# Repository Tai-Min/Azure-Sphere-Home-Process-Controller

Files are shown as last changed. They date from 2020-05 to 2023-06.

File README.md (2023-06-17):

# Azure Sphere Home Process Controller
My entry for [Home Is Where the Hack Is Challenge, with Avnet Azure Sphere](https://www.element14.com/community/docs/DOC-94716?CMP=e-email-ADH-e14-Com-170420-Avnet-2391) (Grand Prize winner!)

Industrial like PID / Two state process controller with web based configuration, MQTT communication and Azure IoT Central integration.

This repository contains source code for both High level application and real time core of Azure Sphere board, source codes for Arduino expansion cards, electronic design files for KiCad, housing design files for Autodesk Inventor and STL files for 3d printing.

For details how it was created and how to use it click [here](https://www.element14.com/community/groups/azuresphere/blog/2020/05/29/azure-sphere-home-process-controller)

Controller image

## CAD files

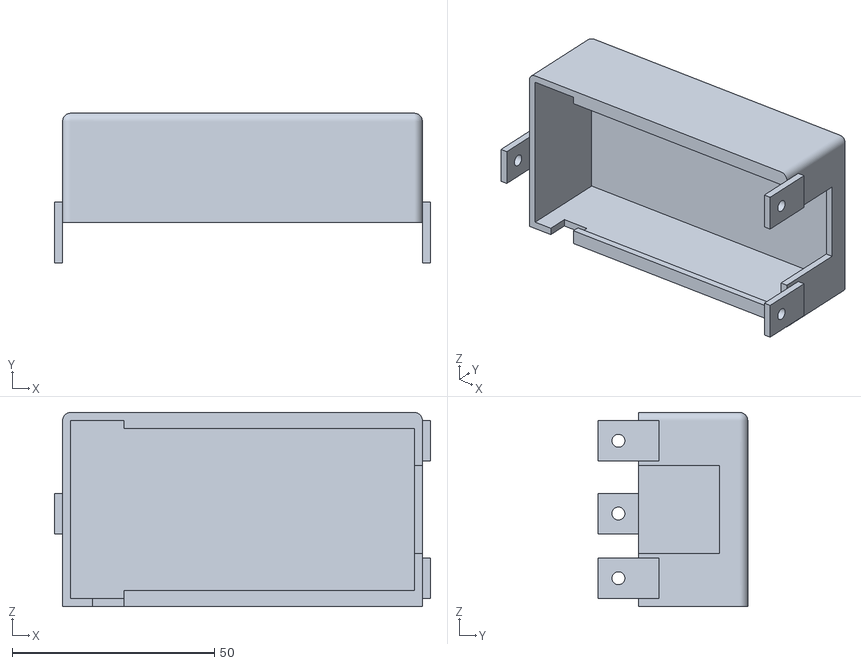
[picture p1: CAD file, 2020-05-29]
Addons/Input/case/stl/top.stl
93.0 x 37.0 x 48.0

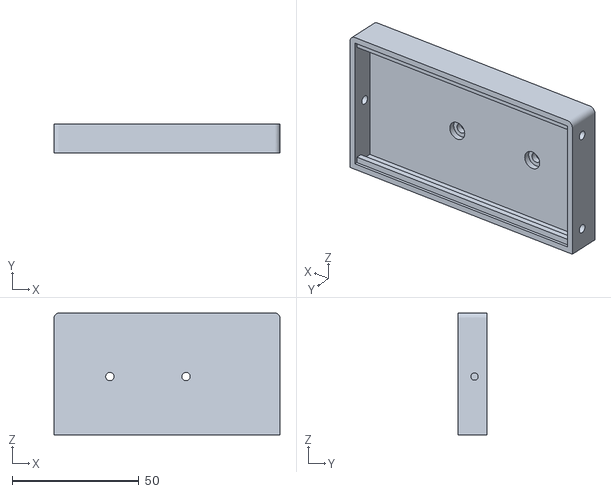
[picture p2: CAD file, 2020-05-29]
Addons/Output/case/stl/bottom.stl
89.0 x 11.6 x 48.0

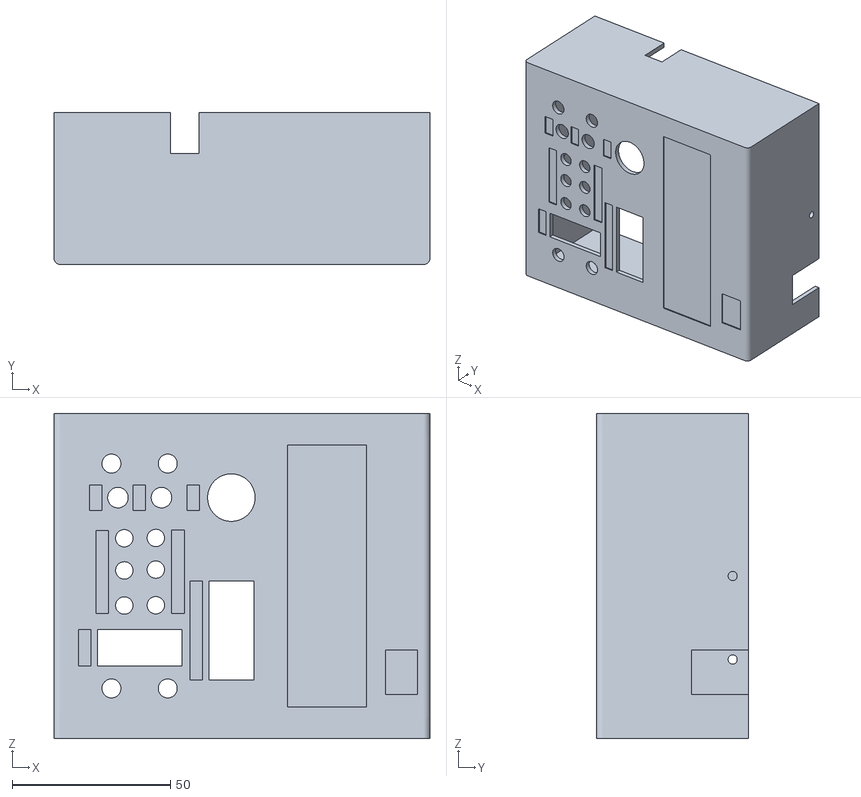
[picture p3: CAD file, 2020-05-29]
Controller/case/stl/case_top.stl
118.7 x 48.0 x 102.8

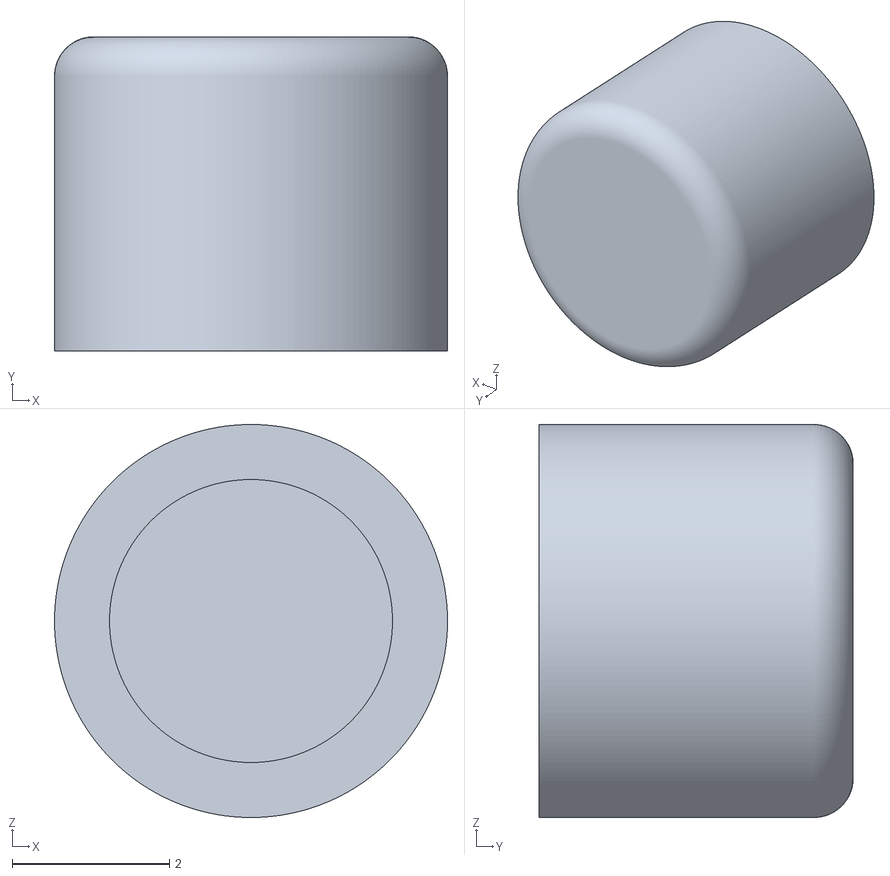
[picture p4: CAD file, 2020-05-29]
Controller/case/stl/button.stl
5.00 x 4.00 x 5.00

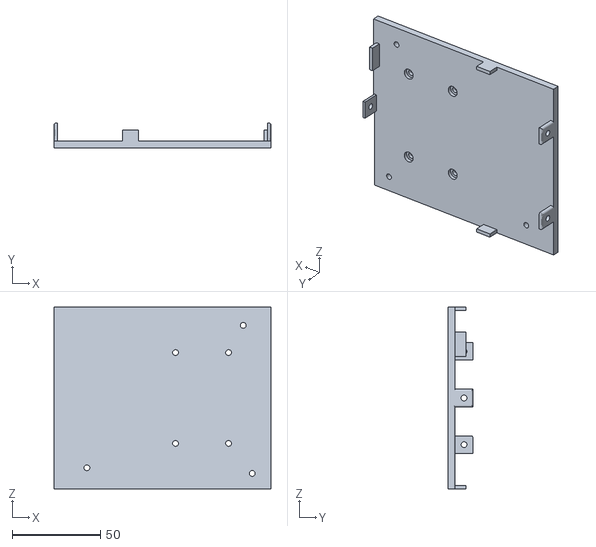
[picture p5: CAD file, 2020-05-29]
Controller/case/stl/case_bottom.stl
122.7 x 14.0 x 102.8

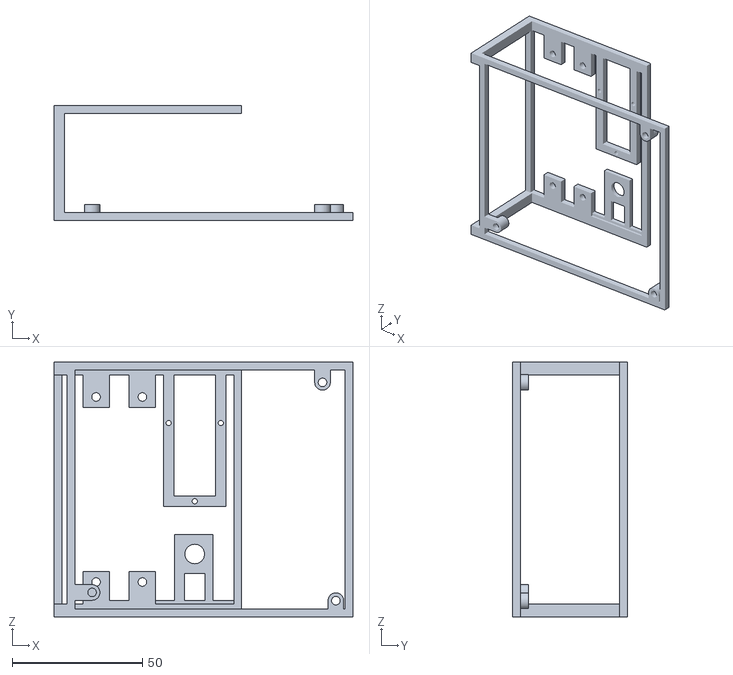
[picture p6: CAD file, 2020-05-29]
Controller/case/stl/electronic_holder.stl
114.7 x 44.0 x 97.7

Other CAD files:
Addons/Input/case/stl/bottom.stl
Addons/Output/case/stl/top.stl
Addons/Input/case/DIN_mount.ipt
Addons/Input/case/SHCS M3-20.ipt
Addons/Input/case/bottom.ipt
Addons/Input/case/input_assembly.iam
Addons/Input/case/top.ipt
Addons/Output/case/DIN_mount.ipt
Addons/Output/case/SHCS M3-20.ipt
Addons/Output/case/bottom.ipt
Addons/Output/case/output_assembly.iam
Addons/Output/case/top.ipt
Controller/case/4Digit_7Segment_LED_Display v8.ipt
Controller/case/BAR1_Fusion_sp_5EABBA22.ipt
Controller/case/Board_Geoms_8195.iam
Controller/case/D1_LED_D5.0mm_5EABBA34.ipt
Controller/case/D2_LED_D5.0mm_5EABBC42.ipt
Controller/case/D3_LED_D5.0mm_5EABBA58.ipt
Controller/case/D4_LED_D5.0mm_5EABBD40.ipt
Controller/case/D5_LED_D5.0mm_5EABBA7C.ipt
Controller/case/D6_LED_D5.0mm_5EABBA8E.ipt
Controller/case/DIN_mount.ipt
Controller/case/PCB_Sketch_8195.ipt
Controller/case/Pcb_8195.ipt
Controller/case/SHCS M3-20.ipt
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

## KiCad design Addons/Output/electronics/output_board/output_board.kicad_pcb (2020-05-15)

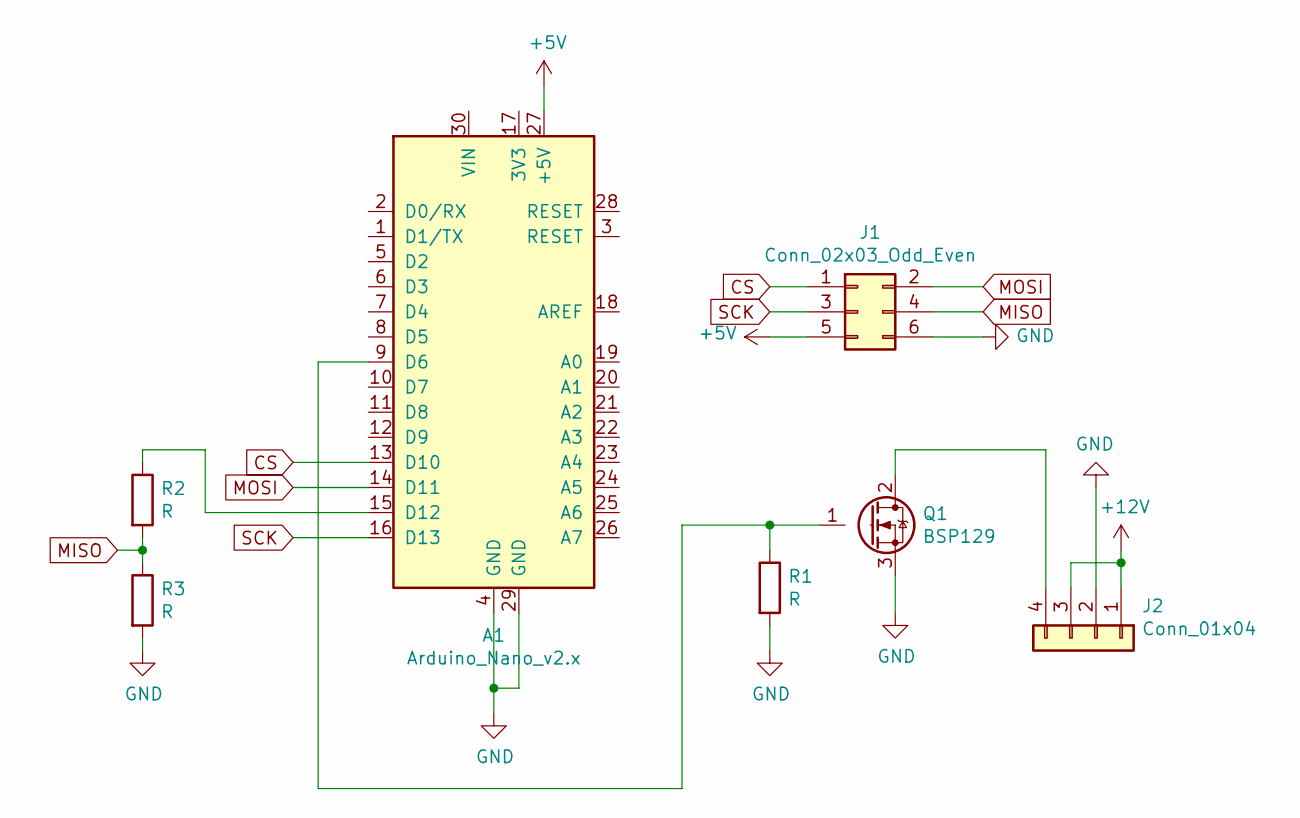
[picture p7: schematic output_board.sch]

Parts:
A1: Arduino_Nano_v2.x; Arduino_Nano
J1: Conn_02x03_Odd_Even; PinSocket_2x03_P2.54mm_Horizontal
J2: Conn_01x04; PhoenixContact_MSTBA_2,5_4-G-5,08_1x04_P5.08mm_Horizontal
Q1: BSP129; TO-220-3_Vertical
R1, R2, R3: R; R_Axial_DIN0207_L6.3mm_D2.5mm_P10.16mm_Horizontal

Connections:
+5V: A1.27 (+5V), J1.5
+12V: J2.1, J2.3
CS: A1.13 (D10), J1.1
GND: A1.4 (GND), A1.29 (GND), J1.6, J2.2, Q1.3 (S), R1.2, R3.2
MISO: J1.4, R2.2, R3.1
MOSI: A1.14 (D11), J1.2
unnamed: A1.9 (D6), Q1.1 (G), R1.1
unnamed: A1.15 (D12), R2.1
unnamed: J2.4, Q1.2 (D)
SCK: A1.16 (D13), J1.3

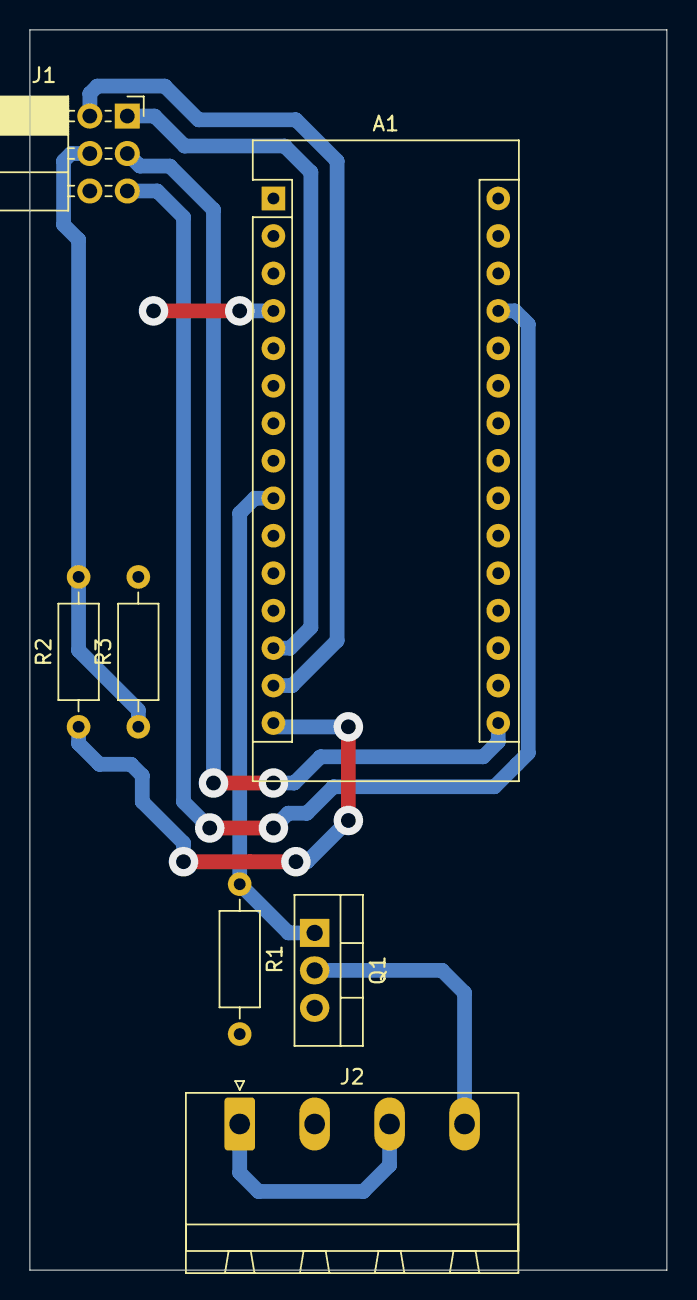
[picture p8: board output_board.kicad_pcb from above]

Board: 2 copper layers, 43.2 x 84.1 mm, 7 parts (0 on the bottom side), 10 nets.

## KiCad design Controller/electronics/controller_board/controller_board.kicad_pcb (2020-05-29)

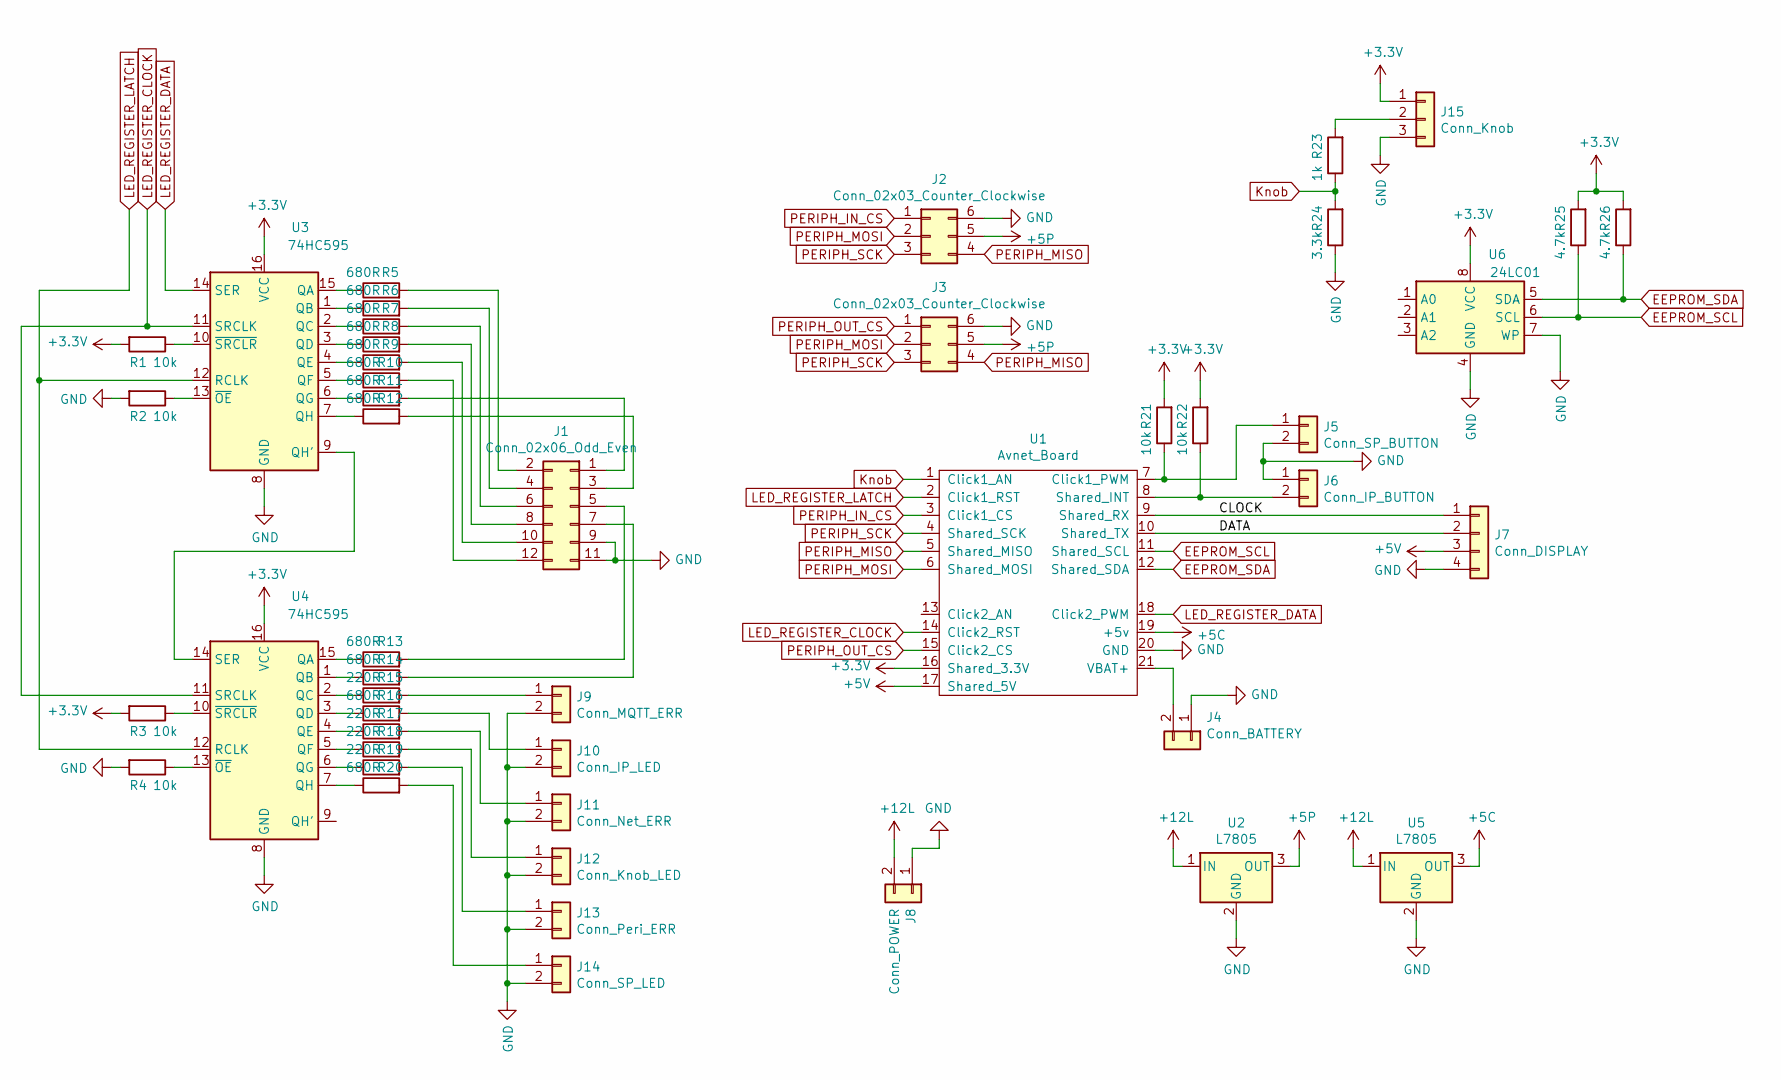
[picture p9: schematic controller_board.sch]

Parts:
J1: Conn_02x06_Odd_Even; PinHeader_2x06_P2.54mm_Vertical
J2: Conn_02x03_Counter_Clockwise; PinSocket_2x03_P2.54mm_Horizontal
J3: Conn_02x03_Counter_Clockwise; PinHeader_2x03_P2.54mm_Horizontal
J4: Conn_BATTERY; PinHeader_1x02_P2.54mm_Vertical
J5: Conn_SP_BUTTON; PinHeader_1x02_P2.54mm_Vertical
J6: Conn_IP_BUTTON; PinHeader_1x02_P2.54mm_Vertical
J7: Conn_DISPLAY; PinHeader_1x04_P2.54mm_Vertical
J8: Conn_POWER; PhoenixContact_MSTBA_2,5_2-G_1x02_P5.00mm_Horizontal
J9: Conn_MQTT_ERR; PinHeader_1x02_P2.54mm_Vertical
J10: Conn_IP_LED; PinHeader_1x02_P2.54mm_Vertical
J11: Conn_Net_ERR; PinHeader_1x02_P2.54mm_Vertical
J12: Conn_Knob_LED; PinHeader_1x02_P2.54mm_Vertical
J13: Conn_Peri_ERR; PinHeader_1x02_P2.54mm_Vertical
J14: Conn_SP_LED; PinHeader_1x02_P2.54mm_Vertical
J15: Conn_Knob; PinHeader_1x03_P2.54mm_Vertical
R1, R2, R3, R4, R21, R22: 10k; R_Axial_DIN0207_L6.3mm_D2.5mm_P10.16mm_Horizontal
R5, R6, R7, R8, R9, R10, R11, R12, R13, R14, R16, R20: 680R; R_Axial_DIN0207_L6.3mm_D2.5mm_P10.16mm_Horizontal
R15, R17, R18, R19: 220R; R_Axial_DIN0207_L6.3mm_D2.5mm_P10.16mm_Horizontal
R23: 1k; R_Axial_DIN0207_L6.3mm_D2.5mm_P10.16mm_Horizontal
R24: 3.3k; R_Axial_DIN0207_L6.3mm_D2.5mm_P10.16mm_Horizontal
R25, R26: 4.7k; R_Axial_DIN0207_L6.3mm_D2.5mm_P10.16mm_Horizontal
U1: Avnet_Board; Avnet_Azure_Sphere
U2, U5: L7805; TO-220-3_Vertical
U3, U4: 74HC595; DIP-16_W7.62mm_LongPads
U6: 24LC01; DIP-8_W7.62mm_LongPads

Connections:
+3V3: J15.1, R1.2, R3.2, R21.2, R22.2, R25.2, R26.2, U1.16 (Shared_3.3V), U3.16 (VCC), U4.16 (VCC), U6.8 (VCC)
+5C: U1.19 (+5v), U5.3 (OUT)
+5P: J2.5, J3.5, U2.3 (OUT)
+5V: J7.3, U1.17 (Shared_5V)
+12L: J8.2, U2.1 (IN), U5.1 (IN)
/CLOCK: J7.1, U1.9 (Shared_RX)
/DATA: J7.2, U1.10 (Shared_TX)
EEPROM_SCL: R25.1, U1.11 (Shared_SCL), U6.6 (SCL)
EEPROM_SDA: R26.1, U1.12 (Shared_SDA), U6.5 (SDA)
GND: J1.9, J1.11, J2.6, J3.6, J4.1, J5.2, J6.1, J7.4, J8.1, J9.2, J10.2, J11.2, J12.2, J13.2, J14.2, J15.3, R2.2, R4.2, R24.1, U1.20 (GND), U2.2 (GND), U3.8 (GND), U4.8 (GND), U5.2 (GND), U6.4 (GND), U6.7 (WP)
Knob: R23.1, R24.2, U1.1 (Click1_AN)
LED_REGISTER_CLOCK: U1.14 (Click2_RST), U3.11 (SRCLK), U4.11 (SRCLK)
LED_REGISTER_DATA: U1.18 (Click2_PWM), U3.14 (SER)
LED_REGISTER_LATCH: U1.2 (Click1_RST), U3.12 (RCLK), U4.12 (RCLK)
unnamed: J1.1, R11.2
unnamed: J1.2, R5.2
unnamed: J1.3, R12.2
unnamed: J1.4, R6.2
unnamed: J1.5, R13.2
unnamed: J1.6, R7.2
unnamed: J1.7, R14.2
unnamed: J1.8, R8.2
unnamed: J1.10, R9.2
unnamed: J1.12, R10.2
unnamed: J4.2, U1.21 (VBAT+)
unnamed: J5.1, R21.1, U1.7 (Click1_PWM)
unnamed: J6.2, R22.1, U1.8 (Shared_INT)
unnamed: J9.1, R15.2
unnamed: J10.1, R16.2
unnamed: J11.1, R17.2
unnamed: J12.1, R18.2
unnamed: J13.1, R19.2
unnamed: J14.1, R20.2
unnamed: J15.2, R23.2
unnamed: R1.1, U3.10 (~SRCLR)
unnamed: R2.1, U3.13 (~OE)
unnamed: R3.1, U4.10 (~SRCLR)
unnamed: R4.1, U4.13 (~OE)
unnamed: R5.1, U3.15 (QA)
unnamed: R6.1, U3.1 (QB)
unnamed: R7.1, U3.2 (QC)
unnamed: R8.1, U3.3 (QD)
unnamed: R9.1, U3.4 (QE)
unnamed: R10.1, U3.5 (QF)
unnamed: R11.1, U3.6 (QG)
unnamed: R12.1, U3.7 (QH)
unnamed: R13.1, U4.15 (QA)
unnamed: R14.1, U4.1 (QB)
unnamed: R15.1, U4.2 (QC)
unnamed: R16.1, U4.3 (QD)
unnamed: R17.1, U4.4 (QE)
unnamed: R18.1, U4.5 (QF)
unnamed: R19.1, U4.6 (QG)
unnamed: R20.1, U4.7 (QH)
unnamed: U3.9 (QH'), U4.14 (SER)
PERIPH_IN_CS: J2.1, U1.3 (Click1_CS)
PERIPH_MISO: J2.4, J3.4, U1.5 (Shared_MISO)
PERIPH_MOSI: J2.2, J3.2, U1.6 (Shared_MOSI)
PERIPH_OUT_CS: J3.1, U1.15 (Click2_CS)
PERIPH_SCK: J2.3, J3.3, U1.4 (Shared_SCK)

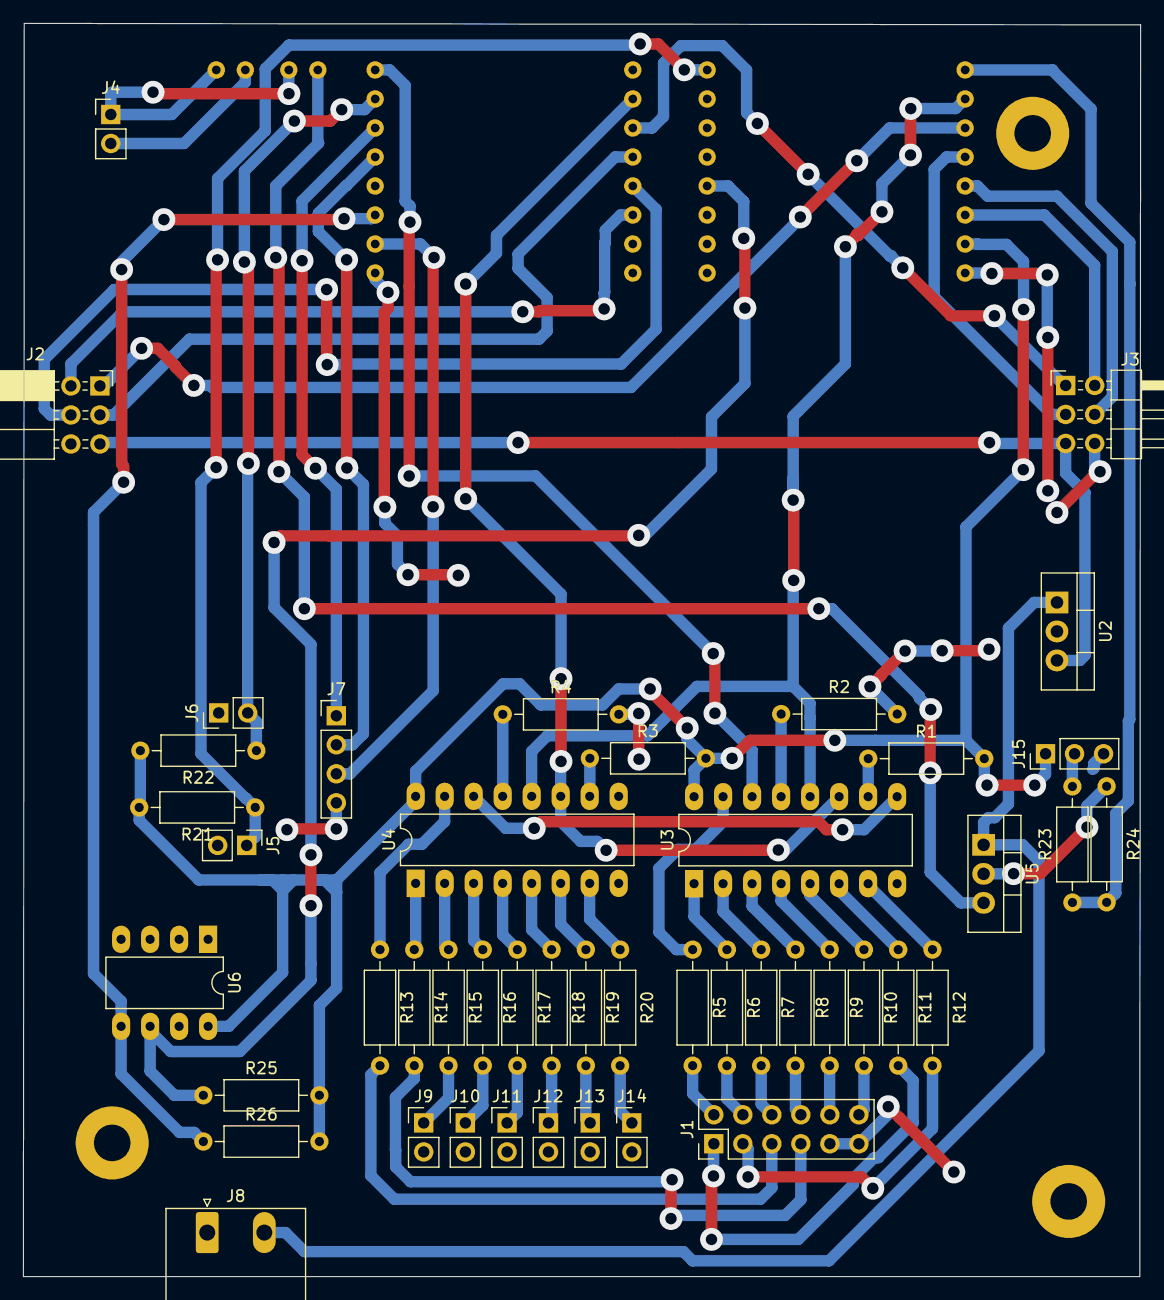
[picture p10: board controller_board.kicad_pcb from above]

Board: 2 copper layers, 97.8 x 109.7 mm, 50 parts (1 on the bottom side), 60 nets.

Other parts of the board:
 : MountingHole_3.2mm_M3_Pad
  : MountingHole_3.2mm_M3_Pad
 #2: MountingHole_3.2mm_M3_Pad

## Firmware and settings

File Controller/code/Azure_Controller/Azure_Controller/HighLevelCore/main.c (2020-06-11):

#include <ctype.h>
#include <string.h>
#include <stdio.h>
#include <signal.h>
#include <errno.h>
#include <stdlib.h>

#include "applibs_versions.h"
#include <applibs/log.h>
#include <applibs/networking.h>

#include "eventloop_timer_utilities.h"

#include "common.h"
#include "mqtt_utilities.h"
#include "http_utilities.h"
#include "mailbox_utilities.h"
#include "network_utilities.h"
#include "config_structs.h"
#include "website.h"
#include "cloud.h"


#define MQTT_PUBLISH_PERIOD 10
#define CLOUD_PUBLISH_PERIOD 60 

typedef enum {
    ExitCode_Success = 0,
    ExitCode_TermHandler_SigTerm = 1,
    ExitCode_TimerHandler_Consume = 2,
    ExitCode_Init_EventLoop = 3,
    ExitCode_Init_Timer = 4,
    ExitCode_Main_EventLoopFail = 5,
    ExitCode_Init_Mailbox = 6,
    ExitCode_Init_HTTP =7
} ExitCode;

static EventLoop* eventLoop = NULL;
static volatile sig_atomic_t exitCode = ExitCode_Success;

int main(int argc, char* argv[]);

/**
* @brief Signal handler for termination requests.
* 
* @param signalNumber Unused.
*/
static void TerminationHandler(int signalNumber);

/**
* @brief Init event loop, timers, mailbox and http server.
*
* @return ExitCode_Success on success, other ExitCode on failure.
*/
static ExitCode InitHandlers(void);

/**
* @brief Close event loop, dispose timers, close MQTT, HTTP server and mailbox.
*/
static void CloseHandlers(void);

/* cloud */
/**
* @brief Periodically called to send diagnostic info to Azure cloud services.
*
* @param timer Pointer to timer to consume and restart.
*/
static void cloudPublishTimerEventHandler(EventLoopTimer* timer);
static EventLoopTimer* publishCloudMsgTimer = NULL;
static int telemetryCount = 0;
static struct timespec azureTelemetryPeriod;

/* website */
/**
* @brief Callback received from HTTP server when GET method has been received.
*
* @param siteLocation String that contains site location. i.e /config.
* @param argKeys Keys from key-value pair passed to GET method after ? symbol.
* @param argValues Values from key-value pair passed to GET method after ? symbol.
* @return Pointer to internal buffer that holds website data to be sent to client.
*/
static const char* HTTP_GET_MethodCallback(char siteLocation[21], bool hasParams, char argKeys[20][31], char argValues[20][31]);

/**
* @brief Parse params received from GET request
*
* @param argKeys Keys from key-value pair passed to GET method after ? symbol.
* @param argValues Values from key-value pair passed to GET method after ? symbol.
*/
static void parseGETParams(char argKeys[20][31], char argValues[20][31]);

/* mqtt */
/**
* @brief Periodically called to send setpoint and process value to MQTT broker.
*
* @param timer Pointer to timer to consume and restart.
*/
static void mqttPublishTimerEventHandler(EventLoopTimer* timer);

/**
* @brief Called when device receives data from subscribed setpoint topic.
* 
* @param topic Name of topic from which message has come.
* @param msg Message.
*/
static void mqttSubscribeCallback(char* topic, char* msg);
static EventLoopTimer* publishMQTTMsgTimer = NULL;
static struct MQTTConfig mqttConf = {
    .processValueTopic = "\0",
    .setpointTopic = "\0",
    .brokerIPAddress = "\0"
};
static bool reloadMQTT = false;

int main(int argc, char*argv[])
{
    if (argc > 1) {
        setCloudScopeId(argv[1]);
    }
    else {
        Log_Debug("Cloud scope is required to run this application.\n");
        return -1;
    }

    waitMs(2000);// wait a bit for real time core to set up stuff

    signal(SIGPIPE, SIG_IGN);

    exitCode = InitHandlers();

    while (exitCode == ExitCode_Success) {
        EventLoop_Run_Result result = EventLoop_Run(eventLoop, -1, true);

        // errno in case of breakpoint
        if (result == EventLoop_Run_Failed && errno != EINTR) {
            exitCode = ExitCode_Main_EventLoopFail;
        }
    }

    CloseHandlers();
    Log_Debug("Application exiting\n");
    return exitCode;
}

static void TerminationHandler(int signalNumber)
{
    exitCode = ExitCode_TermHandler_SigTerm;
}

static ExitCode InitHandlers(void)
{
    struct sigaction action;
    memset(&action, 0, sizeof(struct sigaction));
    action.sa_handler = TerminationHandler;
    sigaction(SIGTERM, &action, NULL);

    eventLoop = EventLoop_Create();
    if (eventLoop == NULL) {
        Log_Debug("Could not create event loop.\n");
        return ExitCode_Init_EventLoop;
    }

    // Callback for MQTT subscribe
    MQTTRegisterSubscribeCallback(mqttSubscribeCallback);

    // Init config http server
    if (httpServerInit() == -1) {
        return ExitCode_Init_HTTP;
    }
    registerGETCallback(HTTP_GET_MethodCallback);

    // Init communication with RT Core
    if (mailboxInit() == -1) {
        return ExitCode_Init_Mailbox;
    }

    // Register a ten second timer to publish setpoint and pv to mqtt broker
    static const struct timespec sendPeriodMQTT = { .tv_sec = MQTT_PUBLISH_PERIOD, .tv_nsec = 0 };
    publishMQTTMsgTimer = CreateEventLoopPeriodicTimer(eventLoop, &mqttPublishTimerEventHandler, &sendPeriodMQTT);
    if (publishMQTTMsgTimer == NULL) {
        return ExitCode_Init_Timer;
    }

    // Register timer to send data to cloud
    azureTelemetryPeriod.tv_sec = getCloudPollPeriodSeconds();
    publishCloudMsgTimer = CreateEventLoopPeriodicTimer(eventLoop, &cloudPublishTimerEventHandler, &azureTelemetryPeriod);
    if (publishCloudMsgTimer == NULL) {
        return ExitCode_Init_Timer;
    }

    return ExitCode_Success;
}

static void CloseHandlers(void)
{
    DisposeEventLoopTimer(publishMQTTMsgTimer);
    DisposeEventLoopTimer(publishCloudMsgTimer);

    EventLoop_Close(eventLoop);

    MQTTStop();
    MQTTKillSubthread();
    httpServerStop();
    httpServerKillSubthread();
    mailboxStop();
}

static void cloudPublishTimerEventHandler(EventLoopTimer* timer) {
    if (ConsumeEventLoopTimerEvent(timer) != 0) {
        exitCode = ExitCode_TimerHandler_Consume;
        return;
    }

    bool isNetworkReady = false;
    if (Networking_IsNetworkingReady(&isNetworkReady) != -1) {
        if (isNetworkReady && !isCloudAuthenticated()) {
            SetupAzureClient();
        }
    }

    if (isCloudAuthenticated()) {
        telemetryCount++;
        if (telemetryCount == CLOUD_PUBLISH_PERIOD) {
            telemetryCount = 0;
            char telemetryBuf[128];
            double sp, pv;
            getSpPv(&sp, &pv);
            snprintf(telemetryBuf, 128, "{\"Setpoint\": \"%f\", \"ProcessValue\": \"%f\"}", sp, pv);
            sendTelemetryToCloud(telemetryBuf);
        }
        doCloudLLWork();
    }
    else {
    }

    // update telemetry period
    azureTelemetryPeriod.tv_sec = getCloudPollPeriodSeconds();
    SetEventLoopTimerPeriod(timer, &azureTelemetryPeriod);
}

static const char* HTTP_GET_MethodCallback(char siteLocation[21], bool hasParams, char argKeys[20][31], char argValues[20][31]) {
    static char buf[4096];
    Log_Debug("GET callback\n");
    Log_Debug("%s\n", siteLocation);
    if (strcmp(siteLocation, "/config") == 0) {
        Log_Debug("config website\n");

        if (hasParams) {
            parseGETParams(argKeys, argValues);
        }

        double sp, pv;
        getSpPv(&sp, &pv);
        struct MQTTConfig mqttConf = mqttConfigLoad();
        struct InputPeriphConfig iconf;
        struct OutputPeriphConfig oconf;
        struct ControllerConfig cconf;
        controlConfigLoad(&iconf, &oconf, &cconf);
        const char* selectedNONE = cconf.controllerType == NONE ? "selected=\"selected\"" : "";
        const char* selectedPID = cconf.controllerType == PID ? "selected=\"selected\"" : "";
        const char* selectedTS = cconf.controllerType == TWO_STATE ? "selected=\"selected\"" : "";
        Log_Debug("IF name: %s\n", getSavedNetworkInterfaceName());
        snprintf(buf, 4096, page, sp,getSavedNetworkInterfaceName(),"111111",mqttConf.brokerIPAddress,mqttConf.setpointTopic,mqttConf.processValueTopic,
            iconf.inputMinValue,iconf.inputMaxValue,oconf.outputMinValue,oconf.outputMaxValue,selectedNONE, selectedTS,selectedPID, 
            cconf.controllerConfig.twoStateConfig.bottomSwitchBoundary, cconf.controllerConfig.twoStateConfig.topSwitchBoundary,
            cconf.controllerConfig.twoStateConfig.offValue, cconf.controllerConfig.twoStateConfig.onValue,
            cconf.controllerConfig.PIDConfig.kp, cconf.controllerConfig.PIDConfig.ki, cconf.controllerConfig.PIDConfig.kd,
            cconf.controllerConfig.PIDConfig.saturationLower, cconf.controllerConfig.PIDConfig.saturarionUpper);
    }
    else {
        Log_Debug("other website\n");
        memcpy(buf, nfound, strlen(nfound)+1);
        
    }
    return buf;
}


static void parseGETParams(char argKeys[20][31], char argValues[20][31]) {

    struct MQTTConfig mqttConf = mqttConfigLoad();
    struct InputPeriphConfig iconf;
    struct OutputPeriphConfig oconf;
    struct ControllerConfig cconf;
    char ssid[31] = "USER_NET\0";
    char psk[31] = "12345678\0";
    bool setWIFI = false;

    for (uint8_t i = 0; i < 20; i++) {
        if (strcmp(argKeys[i], "setpoint") == 0) {
            setSp(atof(argValues[i]));
        }
        else if (strcmp(argKeys[i], "ssid") == 0) {
            memcpy(ssid, argValues[i], strlen(argValues[i]) + 1);
            //Log_Debug("Received IF name: %s\n", ssid);
        }
        else if (strcmp(argKeys[i], "psk") == 0) {
            if (strcmp(argValues[i], "111111") != 0) {
                memcpy(psk, argValues[i], strlen(argValues[i]) + 1);
                setWIFI = true;
            }
        }
        else if (strcmp(argKeys[i], "brokerip") == 0) {
            memcpy(mqttConf.brokerIPAddress, argValues[i], strlen(argValues[i])+1);
        }
        else if (strcmp(argKeys[i], "sptopic") == 0) {
            memcpy(mqttConf.setpointTopic, argValues[i], strlen(argValues[i]) + 1);
        }
        else if (strcmp(argKeys[i], "pvtopic") == 0) {
            memcpy(mqttConf.processValueTopic, argValues[i], strlen(argValues[i]) + 1);
        }
        else if (strcmp(argKeys[i], "inputmin") == 0) {
            iconf.inputMinValue = atof(argValues[i]);
        }
        else if (strcmp(argKeys[i], "inputmax") == 0) {
            iconf.inputMaxValue = atof(argValues[i]);
        }
        else if (strcmp(argKeys[i], "outputmin") == 0) {
            oconf.outputMinValue = atof(argValues[i]);
        }
        else if (strcmp(argKeys[i], "outputmax") == 0) {
            oconf.outputMaxValue = atof(argValues[i]);
        }
        else if (strcmp(argKeys[i], "selectedcontroller") == 0) {
            if (strcmp(argValues[i], "None") == 0)
                cconf.controllerType = NONE;
            if (strcmp(argValues[i], "Two+State") == 0) {
                cconf.controllerType = TWO_STATE;
                for (uint8_t j = 0; j < 20; j++) {
                    if (strcmp(argKeys[j], "tstoggleoff") == 0) {
                        cconf.controllerConfig.twoStateConfig.bottomSwitchBoundary = atof(argValues[j]);
                    }
                    else if (strcmp(argKeys[j], "tstoggleon") == 0) {
                        cconf.controllerConfig.twoStateConfig.topSwitchBoundary = atof(argValues[j]);
                    }
                    else if (strcmp(argKeys[j], "tsoffoutput") == 0) {
                        cconf.controllerConfig.twoStateConfig.offValue = atof(argValues[j]);
                    }
                    else if (strcmp(argKeys[j], "tsonoutput") == 0) {
                        cconf.controllerConfig.twoStateConfig.onValue = atof(argValues[j]);
                    }
                }
            }
            if (strcmp(argValues[i], "PID") == 0) {
                cconf.controllerType = PID;
                for (uint8_t j = 0; j < 20; j++) {
                    if (strcmp(argKeys[j], "pidkp") == 0) {
                        cconf.controllerConfig.PIDConfig.kp = atof(argValues[j]);
                    }
                    else if (strcmp(argKeys[j], "pidki") == 0) {
                        cconf.controllerConfig.PIDConfig.ki = atof(argValues[j]);
                    }
                    else if (strcmp(argKeys[j], "pidkd") == 0) {
                        cconf.controllerConfig.PIDConfig.kd = atof(argValues[j]);
                    }
                    else if (strcmp(argKeys[j], "pidlowsat") == 0) {
                        cconf.controllerConfig.PIDConfig.saturationLower = atof(argValues[j]);
                    }
                    else if (strcmp(argKeys[j], "pidupsat") == 0) {
                        cconf.controllerConfig.PIDConfig.saturarionUpper = atof(argValues[j]);
                    }
                }
            }
        }
    }
    mqttConfigSave(mqttConf);
    reloadMQTT = true;
    controlConfigSave(iconf, oconf, cconf);
    if (setWIFI)
        updateUserDefinedNetwork(ssid, psk);
}

static void mqttPublishTimerEventHandler(EventLoopTimer* timer)
{
    if (ConsumeEventLoopTimerEvent(timer) != 0) {
        exitCode = ExitCode_TimerHandler_Consume;
        return;
    }

    if (!isNetworkConnected()) {
        mqttErrorSet();
        networkErrorSet();
        MQTTStop();
        return;
    }
    else {
        ipAddressKeep(getIPAddress());
        networkErrorClear();
    }

    if (!strcmp(mqttConf.brokerIPAddress, "")) {
        mqttConf = mqttConfigLoad();
        Log_Debug("MQTT config loaded as: SP topic: %s, PV topic: %s, Broker ip: %s\n", mqttConf.setpointTopic, mqttConf.processValueTopic, mqttConf.brokerIPAddress);
    }

    if (reloadMQTT) {
        MQTTStop();
        mqttConf = mqttConfigLoad();
        reloadMQTT = false;
        waitMs(50);
    }

    if (!MQTTIsActiveConnection()) {
        int res = MQTTInit(mqttConf.brokerIPAddress, "1883", mqttConf.setpointTopic);
        if (res) {
            mqttErrorSet();
            return;
        }
        mqttErrorClear();
        waitMs(50);
    }

    double sp, pv;
    getSpPv(&sp, &pv);
    char buf[100];
    snprintf(buf, 100, "%f", sp);
    if (MQTTPublish(mqttConf.setpointTopic, buf) != 0) {
        mqttErrorSet();
        MQTTStop();
    }

    snprintf(buf, 100, "%f", pv);
    if (MQTTPublish(mqttConf.processValueTopic, buf) != 0) {
        mqttErrorSet();
        MQTTStop();
    }
    else {
        mqttErrorClear();
    }
}

static void mqttSubscribeCallback(char* topic, char* msg) {
    if (strcmp(topic, mqttConf.setpointTopic) == 0) {
        setSp(atof(msg));
    }
}

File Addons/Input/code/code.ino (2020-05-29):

#include "pins_arduino.h"
#include <HCSR04.h>

#define BYTES_PER_FRAME 6
#define NUMBER_OF_INPUTS 1

int triggerPin = 3;
int echoPin = 4;
UltraSonicDistanceSensor distanceSensor(triggerPin, echoPin);
#define DISTANCE_MAX_CM 31.0
#define DISTANCE_MIN_CM 0.0

static const uint16_t crctable[256] =
{
  0x0000, 0x1189, 0x2312, 0x329B, 0x4624, 0x57AD, 0x6536, 0x74BF,
  0x8C48, 0x9DC1, 0xAF5A, 0xBED3, 0xCA6C, 0xDBE5, 0xE97E, 0xF8F7,
  0x0919, 0x1890, 0x2A0B, 0x3B82, 0x4F3D, 0x5EB4, 0x6C2F, 0x7DA6,
  0x8551, 0x94D8, 0xA643, 0xB7CA, 0xC375, 0xD2FC, 0xE067, 0xF1EE,
  0x1232, 0x03BB, 0x3120, 0x20A9, 0x5416, 0x459F, 0x7704, 0x668D,
  0x9E7A, 0x8FF3, 0xBD68, 0xACE1, 0xD85E, 0xC9D7, 0xFB4C, 0xEAC5,
  0x1B2B, 0x0AA2, 0x3839, 0x29B0, 0x5D0F, 0x4C86, 0x7E1D, 0x6F94,
  0x9763, 0x86EA, 0xB471, 0xA5F8, 0xD147, 0xC0CE, 0xF255, 0xE3DC,
  0x2464, 0x35ED, 0x0776, 0x16FF, 0x6240, 0x73C9, 0x4152, 0x50DB,
  0xA82C, 0xB9A5, 0x8B3E, 0x9AB7, 0xEE08, 0xFF81, 0xCD1A, 0xDC93,
  0x2D7D, 0x3CF4, 0x0E6F, 0x1FE6, 0x6B59, 0x7AD0, 0x484B, 0x59C2,
  0xA135, 0xB0BC, 0x8227, 0x93AE, 0xE711, 0xF698, 0xC403, 0xD58A,
  0x3656, 0x27DF, 0x1544, 0x04CD, 0x7072, 0x61FB, 0x5360, 0x42E9,
  0xBA1E, 0xAB97, 0x990C, 0x8885, 0xFC3A, 0xEDB3, 0xDF28, 0xCEA1,
  0x3F4F, 0x2EC6, 0x1C5D, 0x0DD4, 0x796B, 0x68E2, 0x5A79, 0x4BF0,
  0xB307, 0xA28E, 0x9015, 0x819C, 0xF523, 0xE4AA, 0xD631, 0xC7B8,
  0x48C8, 0x5941, 0x6BDA, 0x7A53, 0x0EEC, 0x1F65, 0x2DFE, 0x3C77,
  0xC480, 0xD509, 0xE792, 0xF61B, 0x82A4, 0x932D, 0xA1B6, 0xB03F,
  0x41D1, 0x5058, 0x62C3, 0x734A, 0x07F5, 0x167C, 0x24E7, 0x356E,
  0xCD99, 0xDC10, 0xEE8B, 0xFF02, 0x8BBD, 0x9A34, 0xA8AF, 0xB926,
  0x5AFA, 0x4B73, 0x79E8, 0x6861, 0x1CDE, 0x0D57, 0x3FCC, 0x2E45,
  0xD6B2, 0xC73B, 0xF5A0, 0xE429, 0x9096, 0x811F, 0xB384, 0xA20D,
  0x53E3, 0x426A, 0x70F1, 0x6178, 0x15C7, 0x044E, 0x36D5, 0x275C,
  0xDFAB, 0xCE22, 0xFCB9, 0xED30, 0x998F, 0x8806, 0xBA9D, 0xAB14,
  0x6CAC, 0x7D25, 0x4FBE, 0x5E37, 0x2A88, 0x3B01, 0x099A, 0x1813,
  0xE0E4, 0xF16D, 0xC3F6, 0xD27F, 0xA6C0, 0xB749, 0x85D2, 0x945B,
  0x65B5, 0x743C, 0x46A7, 0x572E, 0x2391, 0x3218, 0x0083, 0x110A,
  0xE9FD, 0xF874, 0xCAEF, 0xDB66, 0xAFD9, 0xBE50, 0x8CCB, 0x9D42,
  0x7E9E, 0x6F17, 0x5D8C, 0x4C05, 0x38BA, 0x2933, 0x1BA8, 0x0A21,
  0xF2D6, 0xE35F, 0xD1C4, 0xC04D, 0xB4F2, 0xA57B, 0x97E0, 0x8669,
  0x7787, 0x660E, 0x5495, 0x451C, 0x31A3, 0x202A, 0x12B1, 0x0338,
  0xFBCF, 0xEA46, 0xD8DD, 0xC954, 0xBDEB, 0xAC62, 0x9EF9, 0x8F70
};

/* definitions external functions */
double mapFloat(double x, double in_min, double in_max, double out_min, double out_max) {
  if (in_max - in_min == 0)
    return 0;
  double val = (x - in_min) * (out_max - out_min) / (in_max - in_min) + out_min;
  if (val > out_max)
    val = out_max;
  if (val < out_min)
    val = out_min;

  return val;
}

uint16_t CRC16(
  uint16_t crc,      // Seed for CRC calculation
  const void *c_ptr, // Pointer to byte array to perform CRC on
  size_t len)        // Number of bytes to CRC
{
  const uint8_t *c = c_ptr;

  while (len--)
    crc = (crc << 8) ^ crctable[((crc >> 8) ^ *c++)];

  return crc;
}

uint8_t toHighByte(uint16_t wordVal) {
  return wordVal >> 8;
}

uint8_t toLowByte(uint16_t wordVal) {
  return wordVal;
}

void setup (void)
{
  pinMode(MISO, OUTPUT);
  pinMode(SS, INPUT);
  pinMode(MOSI, INPUT);
  pinMode(SCK, INPUT);
  SPCR |= _BV(SPE) | _BV(SPIE);
  //Serial.begin(115200);
}

volatile uint16_t crcs[NUMBER_OF_INPUTS] = {0};
volatile uint8_t currentIndex = 0;
volatile uint16_t measurements[NUMBER_OF_INPUTS] = {0};
volatile uint8_t readPhase = 0;
volatile bool dataReady = false;

ISR (SPI_STC_vect)
{
  if (dataReady) {
    readPhase++;
    if (readPhase > BYTES_PER_FRAME)
      readPhase = 0;
    return;
  }

  if (readPhase == 0)
    currentIndex = SPDR;
  else if (readPhase < 3)
    SPDR = (uint8_t)(measurements[currentIndex] >> (readPhase - 1) * 8);
  else
    SPDR = (uint8_t)(crcs[currentIndex] >> (readPhase - 3) * 8);

  readPhase++;
  if (readPhase >= BYTES_PER_FRAME) {
    readPhase = 0;
    dataReady = true;
  }
}

double previousDistance = 0;
void loop() {
  if (dataReady) {
    //Serial.print("Index: ");
    //Serial.println(currentIndex);
    for (uint8_t i = 0; i < NUMBER_OF_INPUTS; i++) {

      uint8_t vals[3];
      vals[0] = i;
      vals[1] = toLowByte(measurements[i]);
      vals[2] = toHighByte(measurements[i]);
      //Serial.print("MEasurement: ");
      //Serial.println(measurements[0]);
      crcs[i] = CRC16(2137, vals, 3);

      //if(i == currentIndex){
        //Serial.print("CRC: ");
        //Serial.println(crcs[i]);
      //}
    }
    //measurements
    dataReady = false;
    
    double distance = distanceSensor.measureDistanceCm();

    //filtering
    distance = previousDistance + 0.2 * (distance - previousDistance);
    previousDistance = distance;

    //measure water level, not how much distance there is to the bottom
    distance = DISTANCE_MAX_CM - distance;
    
    //saturation
    if(distance > DISTANCE_MAX_CM)
      distance = DISTANCE_MAX_CM;
    if(distance < DISTANCE_MIN_CM)
      distance = DISTANCE_MIN_CM;
    cli();
    measurements[0] = mapFloat(distance, DISTANCE_MIN_CM, DISTANCE_MAX_CM, 0.0, 65535.0);
    sei();
    //dataReady = false;
  }
}

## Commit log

2020-05-15 Global cleanup, add EEPROM
    [4Digit_7Segment_LED_Display v8.ipt, BAR1_Fusion_sp_5EABBA22.ipt, Board_Geoms_8195.iam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]
2020-05-23 comment all the stuff, fix memory leaks
    [button.ipt, case_top.ipt, controller_board.sch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]
2020-05-29 add stl files
    [bottom.ipt, bottom.stl, button.stl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]
2020-06-11 Fix doxygen syntax
    [controller_board.kicad_pcb, controller_board.sch, controller_panel.kicad_pcb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]
